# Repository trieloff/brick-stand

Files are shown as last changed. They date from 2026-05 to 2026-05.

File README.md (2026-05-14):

# brick-stand

Tenting stand for the [ZSA Voyager](https://www.zsa.io/voyager) split keyboard, designed parametrically with [ForgeCAD](https://github.com/KoStard/ForgeCAD).

## Reference geometry

`reference/` contains STL files used as design references — not part of the printable stand:

- `bottom_plate_left.STL` / `bottom_plate_right.STL` — official ZSA Voyager bottom shells (from <https://www.zsa.io/assets/voyager/voyager_stl.zip>)
- `ZSA Voyager Tripod Mount.stl` — [mark's tripod mount](https://www.printables.com/model/607727-zsa-voyager-tripod-mount), reference for the magnet + guide-pin mating pattern

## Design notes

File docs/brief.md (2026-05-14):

# Build Brief — The Brick

A monolithic tenting stand for the ZSA Voyager split keyboard, code-named **The Brick**. Prototyped in FDM print, intended for production as a single-piece stainless steel block (machined billet or investment cast + finish-machined).

## Operating story

Personal product-design project by the designer, Lars Trieloff. The Brick replaces the Voyager's stock magnetic legs with a substantial, monolithic base that holds the keyboard at the designer's measured-from-life typing posture. The prototype is FDM-printed in PLA/PETG for fit validation; the production target is a single-piece stainless-steel base per half — heavy, monolithic, finished. The name is literal: it should look and feel like a brick of metal, not a printed gadget.

**Anti-generic bar:** This is *not* a printable hobby wedge. The brick exists because the designer wants a piece of bench-grade desk hardware: it should feel inevitable, machine-honest, and look as good cast in steel as it does printed in plastic.

## Artifact classification

- **Family:** fixture / personal product, monolithic mating-and-supporting part. Not a mechanism — no moving parts, no assembly.
- **Manufacturing posture (prototype):** FDM print, PETG preferred (PLA acceptable), hollowed with infill.
- **Manufacturing posture (production):** single-piece stainless steel — 3-axis CNC from billet, or investment cast + finish-machined on critical mating surfaces. The geometry must be honestly producible in both processes.
- **Duty:** general-duty (desk use, occasional removal, must survive being dropped on tile from desk height when steel).
- **Scale:** compact (one per keyboard half, fits within keyboard footprint).
- **Cost posture (prototype):** balanced. **Cost posture (production):** performance-first (the brick *is* the cost statement).

## Posture (measured from the designer's current setup)

Left half, three corners measured against desktop:

| Corner | Z above desk |
|---|---|
| Front-left (outer / pinky) | **0 mm** (touching desk) |
| Rear-left (USB-port side) | **17 mm** |
| Front-right (inner / thumb) | **79 mm** |
| Rear-right (derived from plane) | **~96 mm** |

Right half is mirrored.

Derived plane:

- **Tent angle (rotation about front-rear axis):** atan(79 / 138) ≈ **29.8°**, outer-pinky-low, inner-thumb-high.
- **Tilt angle (rotation about left-right axis):** atan(17 / 137) ≈ **7.1°**, rear-raised (typewriter / positive tilt).
- Combined plane normal: `(10823, 2346, -18906)` (unnormalized) in keyboard-local frame.

These angles are **fixed** in the design — no adjustment mechanism. The brick *is* the angle.

## Attachment interface — official ZSA tripod-mount pattern

The brick replicates the interface of ZSA's own tripod-mount plate (which the designer owns and measured). Centered at **(63.10, 81.90)** in the left-half frame. See `docs/geometry-facts.md` for verified positions.

- **4 registration pegs**, Ø 2.15 mm × 1.5 mm tall, at the corners of a **33.26 × 33.26 mm square**. Slip-fit into the four small receptacles in the Voyager bottom plate (verified at z=0.11 in the reference STL).
  - Prototype: pegs printed integral to the brick body.
  - Production: pegs machined integral to the stainless body (or, alternatively, press-fit dowel pins into reamed holes if 3-axis CNC can't reach such fine integral features cleanly; pin choice deferred to manufacturing review).
- **4 magnets**, Ø 5 mm × 2 mm N42 neodymium, in a diamond pattern at **r = 9 mm from zone center**, at the four cardinal directions. Magnet midpoint-to-midpoint between opposing magnets = 18 mm. Pockets are Ø 5.1 mm × 2.1 mm deep, in the top mating face. Magnets pull against the corresponding magnets / steel pucks ZSA placed in the keyboard at matching positions.
- **No central feature engaged.** The keyboard has a ~Ø 3.8 mm tripod-screw recess at the zone center; the brick does not engage this.

The four corner pegs handle XY registration and anti-rotation. The four diamond magnets handle Z retention. No additional alignment features are needed.

## Geometry constraints

- **Footprint envelope:** matches the full Voyager half's vertical projection — 138 × 137 mm. The brick fills the entire shadow under the keyboard. This is intentional: the keyboard sits flush on the brick along its whole base, the brick reads as a chunky block of metal, and the "brick" identity is preserved.
- **Top face:** a single tilted plane at the measured posture, matching the keyboard's bottom plane exactly. Surface continuous edge-to-edge (no raised mating pad — the keyboard rests on the entire top face, with the attachment features sunk into a centered 38 × 38 mm zone).
- **Mating zone** (centered at (63.10, 81.90) in keyboard coords): 4 pegs at the 33.26 × 33.26 mm square corners stick up 1.5 mm from the top face; 4 magnet pockets (Ø 5.1 × 2.1) recessed into the top face in the diamond pattern.
- **Base face:** parallel to the desktop (Z = 0 plane), full flat contact across the whole footprint.
- **Body:** swept/filled volume between top plane and base, with the visual language of a solid milled block — chamfered top edges (2 mm × 45° for steel, 1.5 mm fillet for FDM), perimeter corner radii 6 mm, no visible draft, no decorative ribs. Corner heights: front-pinky 0 mm, rear-pinky 17 mm, front-thumb 79 mm, rear-thumb ~96 mm.
- **Prototype-only:** internal hollowing for FDM printability — target ~3 mm shell wall. External geometry must remain identical to production.
- **Production:** solid stainless steel. Optional machined recess on the bottom (5 mm deep, 5 mm perimeter wall) for mass and 4-point desk contact.

## Feet / desk interface

- Four counter-bored pockets (Ø 10 mm × 2 mm deep) on the bottom face at the four base corners, sized for **3M Bumpon SJ5012** or similar urethane bumper feet. Same pattern for both prototype and production.

## Variant policy

- Single ForgeCAD project produces both halves via a `Side` parameter (`"left"` / `"right"`). Right is a mirror of left about the X axis.
- A `Process` parameter selects `"FDM-prototype"` (hollowed) vs `"steel-production"` (solid with optional bottom recess). Both share the same external geometry.
- Default render: one selected variant at a time. A `Show pair` debug mode renders both halves side-by-side for posture inspection, but collision/manufacturing inspection always runs on one selected variant.

## File organization

Multi-file ForgeCAD project:

- `main.forge.js` — entry point. Top-level `assembly()` selects variant via params, places either one or both halves, renders.
- `brick.forge.js` — the brick geometry itself, parameterized by `Side` and `Process`.
- `voyager_mockup.forge.js` — a low-detail proxy of the Voyager bottom plate (extracted bounding box + corner pin/magnet pattern) used only for collision and posture inspection. Not part of the final BOM.
- `geometry.js` — pure helpers and constants (measured corner heights, magnet pattern, derived plane normal). Plain `.js`, no rendered geometry.

## BOM (production part — one half)

| Item | Spec | Qty | Notes |
|---|---|---|---|
| Brick body | 316 or 304 stainless steel, single piece | 1 | CNC from billet OR investment cast + finish-machined on top mating face, peg posts, magnet pockets, bottom |
| Neodymium magnet | Ø 5 mm × 2 mm, N42, axially magnetized | 4 | Press-fit or epoxy into pockets; polarity to match the keyboard's internal magnets at the same positions |
| Urethane bumper foot | 3M Bumpon SJ5012 (black, Ø 10 × 2 mm) | 4 | Self-adhesive into bottom pockets |

(Prototype BOM: printed body with integral pegs, same magnets, same feet. The 4 corner pegs are integral to the body in both processes — no separate dowel pins.)

## Validation criteria

- Top face places the four Voyager corners at 0/17/79/~96 mm ± 0.5 mm against a flat desk.
- 4 corner pegs fall on the 33.26 × 33.26 mm square at (63.10, 81.90) ± 0.1 mm, slip-fit into the keyboard's peg receptacles.
- 4 magnet pockets at the cardinal r=9 mm positions ± 0.1 mm.
- No collision between brick top face and Voyager underside other than the intended flush contact.
- Center of mass over the base footprint with at least 10 mm safety margin in all directions when keyboard is mounted (tip-over check at 29.8° tent).
- Wall thickness ≥ 3 mm everywhere in the FDM prototype shell. Minimum cross-section ≥ 5 mm everywhere in the production solid.
- Magnet pockets: Ø 5.1 mm × 2.1 mm depth (press-fit). Peg shafts: Ø 2.15 mm × 1.5 mm tall.
- Bottom face flat to ± 0.2 mm prototype / ± 0.05 mm production.

## Final state target

**`BUILD-READY` for the prototype**, **`BEST-EFFORT BUILD CANDIDATE` for production** — the steel manufacturing review (CNC vs cast + finish, integral pegs vs press-fit dowels) needs a real shop quote before final lock.

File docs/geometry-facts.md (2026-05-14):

# Geometry facts (extracted from reference STLs)

All in millimeters, in the **Voyager-left-half local frame** of `reference/bottom_plate_left.STL`:

- **Footprint:** X 0 .. 137.85 (pinky → thumb), Y 0 .. 136.87 (front → rear), plate thickness 2.3 mm.
- **Pinky edge:** X = 0. **Thumb edge:** X = 137.85.
- **Front edge:** Y = 0. **Rear edge:** Y = 136.87.
- The Voyager-right half is the mirror of the left about the X axis.

## ZSA tripod-mount interface (the brick's attachment target)

ZSA ships an official tripod-mount plate (~38 × 38 mm, owned by the designer). It mates centrally to the keyboard via four corner pegs and four diamond-pattern magnets. The brick replicates this same interface on its top face.

**Zone center:** (63.10, 81.90) in left-half frame.

### Peg receptacles (verified in STL)

Four small circular features at z ≈ 0.11 mm, Ø ~2.2 mm, on the corners of a **33.26 × 33.26 mm square** around the zone center:

| Position | (X, Y) |
|---|---|
| Front-pinky corner | (46.50, 65.30) |
| Front-thumb corner | (79.70, 65.30) |
| Rear-thumb corner | (79.70, 98.50) |
| Rear-pinky corner | (46.50, 98.50) |

The brick's matching pegs are ~Ø 2.15 mm × 1.5 mm tall (slip-fit into the keyboard receptacles).

### Magnets (per the designer's measurements of the ZSA mount plate)

Four magnets, **Ø 5 mm**, in a diamond rotated 45° from the corner-peg square. **Midpoint-to-midpoint distance between opposing magnets ≈ 18 mm**, so each magnet sits at **r = 9 mm** from the zone center, at the four cardinal directions:

| Direction | (X, Y) |
|---|---|
| Rear (Y+) | (63.10, 90.90) |
| Thumb (X+) | (72.10, 81.90) |
| Front (Y−) | (63.10, 72.90) |
| Pinky (X−) | (54.10, 81.90) |

These positions are not visible in the bottom-plate STL (magnets are embedded internally, flush with the inner face). Verified geometrically against the designer's measurements of the ZSA tripod-mount plate; depends on the assumption that ZSA placed corresponding magnets in matching positions.

### Central feature

A small (~Ø 3.8 mm) feature at the zone center, likely a tripod-screw recess. The brick top face does not need to engage this — it is irrelevant for the brick's attachment.

### Legacy: magnetic leg sockets (NOT used by the brick)

Two Ø 16.5 mm sockets at (119.24, 13.66) and (105.40, 114.36) accept the stock folding magnetic legs. The brick **replaces** the legs, so these sockets are not engaged.

## Measured posture (user-reported corner heights above the desk)

Mapped from user phrasing to the STL frame:

| Corner | (X, Y) | Z above desk |
|---|---|---|
| Front-pinky ("front-left") | (0, 0) | 0 mm (touching desk) |
| Rear-pinky ("rear-left, USB-port") | (0, 136.87) | 17 mm |
| Front-thumb ("front-right") | (137.85, 0) | 79 mm |
| Rear-thumb (derived) | (137.85, 136.87) | ~96 mm |

## Derived mating plane (in desk frame)

The keyboard's bottom face lies on the plane through those four corners. Closed form:

```
z(x, y) = a*x + b*y
a = 79 / 137.85   ≈ 0.57309
b = 17 / 136.87   ≈ 0.12421
```

- **Tent angle (rotation about Y, front-rear axis):** atan(a) ≈ **29.81°**, thumb-up.
- **Tilt angle (rotation about X, pinky-thumb axis):** atan(b) ≈ **7.08°**, rear-up.
- **Plane normal (toward desk):** proportional to (a, b, −1) = (0.57309, 0.12421, −1).

## Mating-pad heights in posture

The brick's top mating pad sits on the keyboard's bottom plane at the tripod-mount zone center and corners. Z above desk at each:

- **Zone center** (63.10, 81.90): z = 0.57309 · 63.10 + 0.12421 · 81.90 ≈ **46.2 mm**
- Front-pinky corner (46.50, 65.30): z ≈ **34.8 mm**
- Front-thumb corner (79.70, 65.30): z ≈ **53.8 mm**
- Rear-thumb corner (79.70, 98.50): z ≈ **57.9 mm**
- Rear-pinky corner (46.50, 98.50) z ≈ **38.9 mm**

The mating pad (~38 × 38 mm) sits on a tilted plane at these heights and tapers down on a tapered pedestal to the wider desk-contact base.

## Bumper feet pattern (Brick's bottom face)

Four feet, 5 mm inset from each Brick corner, suitable for 3M Bumpon SJ5012 (Ø 10 mm).

## Right-half mirror

To produce the right Brick, mirror everything about X (in the **Voyager-pair** frame where the two halves meet at the user's centerline). The footprint, sockets, and corner-height pattern flip; sign of `a` flips, `b` stays.

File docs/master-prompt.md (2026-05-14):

# Master Prompt — Modeling Pass

```text
You are producing a ForgeCAD build-ready physical artifact package, not a concept sketch.

Treat this as a serious product-team prototype assignment.
The goal is to produce a credible internal engineering package for a real build candidate, not a generic maker example.

Target artifact:
- artifact: monolithic tenting base ("The Brick") for the ZSA Voyager split keyboard, one part per half (mirrored).
- request summary: design a fixed-angle tenting stand that holds the user's measured posture and is honestly producible both as a hollowed FDM print and as a single-piece stainless steel block.
- normalized interpretation: a rigid wedge with a planar upper mating face (Voyager interface) and a planar lower base face (desk interface). No moving parts. Magnet + guide-pin attachment replaces the stock Voyager legs.

Specific operating story:
- organization / team: personal product-design project by the designer (no invented employer).
- project / prototype revision: "Brick v0.1" — first geometry pass for fit validation.
- milestone / review moment: working FDM print at the designer's desk, validated against the in-use Voyager; then sourcing quote for single-piece stainless production.
- domain context: ergonomic keyboard accessories / custom desk hardware.
- production reason: replace stock Voyager magnetic legs with a substantial, monolithic base at a specific measured posture.
- test setting: designer's desk, real Voyager keyboard, real typing session.
- generic-output failure mode to avoid: a printable hobby wedge with hollow ribs that visibly screams "FDM" — must look credible cast or machined in steel.
- benchmark class / public comparison anchor: ZSA's official Voyager printables for the interface pattern; "Brick"-class desk hardware aesthetic (single milled block, chamfered edges, generous radii).

Chosen intake classification:
- artifact family: fixture / personal product, monolithic mating-and-supporting part (no mechanism).
- duty level: general-duty.
- scale level: compact (≤ 138 × 137 mm per half).
- cost posture: balanced for prototype, performance-first for production.
- job style: single-piece replacement for the stock Voyager legs.
- manufacturing / process stack: prototype = FDM (PETG preferred, 3–4 mm shell, 15–25 % infill); production = single-piece 304/316 stainless steel via 3-axis CNC from billet, or investment cast + finish-machined on the mating face, magnet pockets, pin holes, and bottom.
- budget posture: prototype cheap, production "as-good-as-it-deserves".

Working assumptions chosen to close missing inputs:
- these assumptions are provisional and family-scoped; they apply to monolithic fixtures / personal product, not as universal defaults.
- Posture is fixed at the designer's measured corner heights: (front-outer, rear-outer, front-inner, rear-inner) = (0, 17, 79, 96) mm on a 138 × 137 mm footprint. Tent ≈ 29.8°, tilt ≈ 7.1° rear-raised.
- Attachment: 5 × Ø10×3 mm N42 magnets press-fit into pockets on the mating face, 4 × Ø3×6 mm hardened dowel pins press-fit (production) or printed integral (prototype). Pattern positions extracted from `reference/bottom_plate_left.STL` — to be verified during implementation.
- Feet: four Ø10×2 mm bottom pockets for 3M Bumpon SJ5012 urethane bumpers.
- External geometry is identical between prototype and production; only the *internal* hollowing differs (prototype = offset shell, production = solid or with optional bottom recess).

Hard constraints:
- use ForgeCAD.
- no `assembly()` for a moving mechanism is required — there is no mechanism. Use `assembly()` only to compose the brick + Voyager mockup for inspection.
- the brick is one solid body; do not split it into multiple parts that would have to be joined.
- choose manufacturing/processes that fit a single-piece stainless production part: no undercuts unreachable by a 3-axis mill from top + bottom, no internal voids that an investment-cast pattern could not realize, no thin protrusions < 3 mm wall.
- include realistic process-appropriate clearances on the magnet pockets and pin holes for both prototype (looser, accommodate FDM expansion) and production (H7 press-fit).
- include manufactured, printed, and purchased parts only where each is an honest choice.
- include a BOM that is concrete enough to buy and assemble from.
- do not hide uncertainty; choose defaults and continue.
- do not claim the designer works for a named company.
- do not clone proprietary named products; mark's tripod mount is a *pattern reference* for the magnet/pin interface, not a design to copy.

Acceptable final states:
1. `BUILD-READY` once the magnet/pin pattern is extracted and verified against the Voyager bottom-plate STL.
2. `BEST-EFFORT BUILD CANDIDATE` if the pattern extraction is approximate.

Required outputs:

0. Operating story and anti-generic bar — already stated above.
1. Problem normalization — already stated above.
2. Assumption bundle — already stated above.
3. Architecture choice
   - One monolithic wedge per half. Upper face = measured-posture plane. Lower face = desk plane (Z=0). Body = swept solid between them, clipped to a chamfered-and-radiused prismatic outline.
   - Rejected: adjustable hinge mechanism (no need, posture is fixed); two-part stacked wedges (defeats the "brick" identity and adds an interface that wants to wobble); minimal three-point post stand (no mass, fails the "feels like a brick" criterion).
4. Detailed mechanical design
   - Footprint outline: chamfered rectangle inscribed in the Voyager projection. Corner radii 6 mm. External top edges chamfered 2 mm × 45° on production, fillet 1.5 mm on prototype (FDM aesthetic).
   - Mating face: defined by the four measured corner heights. Pattern of 5 magnet pockets and 4 pin features mirrors the Voyager bottom-plate sockets.
   - Base face: flat, parallel to desk, with four feet pockets at the corners and (production only) an optional bottom recess.
   - No motion ranges, no joints, no stops.
5. Actuation and transmission — not applicable. The brick is static.
6. Manufacturing package
   - Prototype: FDM, brick lying mating-face-up so the magnet pockets print with clean ceilings via bridging, the base face prints flat against the bed for dimensional accuracy. Single-shell vase-mode-style 3 mm wall thickness, 15 % gyroid infill in a top zone for stiffness. Pin features printed integral, no support required if oriented correctly. Print sensitivities: bottom flatness (first-layer squish), magnet pocket diameter (FDM tends to over-shrink small features — add 0.2 mm radial allowance).
   - Production: 3-axis CNC from a 304 or 316 stainless billet. Two setups: top-down for the angled mating face, magnet pockets, pin reaming, and side chamfers; bottom-up for the base recess and feet pockets. Investment casting alternative: cast near-net, finish-machine the mating face flat-and-true, ream pin holes, drill/bore magnet pockets, surface-grind base flat.
7. Bill of materials — see `docs/brief.md` BOM table. Reproduce inline in the implementation output.
8. Assembly package
   - Production: press magnets into pockets (light tap with arbor press, witness mark on polarity); press dowel pins; peel-and-stick urethane feet onto bottom pockets.
   - Prototype: same, except pins are printed integral so only magnets and feet are pressed/stuck.
9. Validation package
   - Verify mating face places the four Voyager corners at 0/17/79/96 mm ± 0.5 mm.
   - Render-inspect with the Voyager mockup mounted: no collision with USB-C cable strain relief, no collision with the per-half cable boss.
   - Tip-over check: center of mass projected onto base must lie ≥ 5 mm inside the base outline in all directions.
   - Wall thickness: ≥ 3 mm prototype shell, ≥ 5 mm production minimum cross-section.
   - Compare both rendered halves to ensure mirror correctness.
10. ForgeCAD implementation package
    File structure:
    - `main.forge.js` — runnable entry point. Params: `Side` (left/right), `Process` (FDM-prototype / steel-production), `ShowVoyagerMockup` (boolean), `ShowPair` (boolean, debug). Returns either one brick, one brick + mockup, or both bricks side-by-side.
    - `brick.forge.js` — `function brick({ side, process })` returning the solid.
    - `voyager_mockup.forge.js` — `function voyagerMockup({ side })` returning a thin proxy plate at the measured posture.
    - `geometry.js` — pure constants: `CORNER_HEIGHTS_MM`, `FOOTPRINT_MM`, `MAGNET_PATTERN`, `PIN_PATTERN`, `MATING_PLANE_NORMAL`, mirror helper.
    Use `bom()` to declare magnets, pins, feet, and the body. Export STL for prototype, STEP for production.
11. Final verdict
    - `BEST-EFFORT BUILD CANDIDATE` until the magnet/pin pattern is extracted from the Voyager STL with verified positions.

ForgeCAD-specific quality bar:
- The brick is static; no joints required.
- Use `assembly()` only to compose brick + Voyager mockup for inspection — clearance logic must be physically honest there.
- A pretty rendered wedge is not success. Success = collision-clean inspection bundle against the Voyager mockup, all four corner heights verified, and a BOM that someone could quote against today.
```

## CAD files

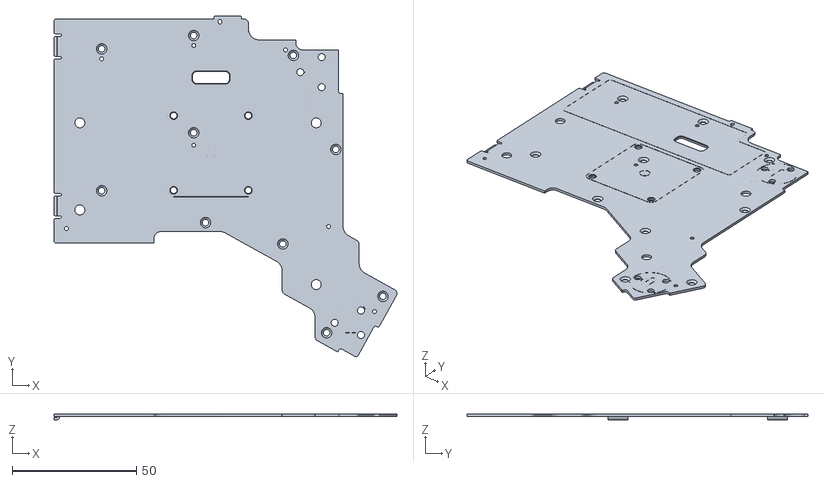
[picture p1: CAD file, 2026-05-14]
reference/bottom_plate_right.STL
137.8 x 136.9 x 2.32

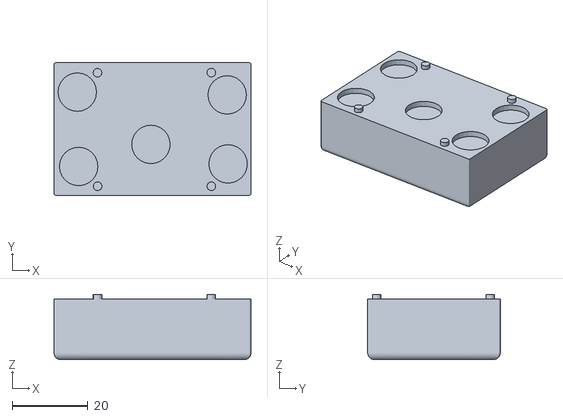
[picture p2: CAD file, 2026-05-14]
reference/ZSA Voyager Tripod Mount.stl
52.0 x 35.0 x 17.2

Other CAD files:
reference/bottom_plate_left.STL

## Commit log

2026-05-14 Initial commit: Voyager tenting stand project scaffold
    Reference STLs from ZSA (shell) and Printables (tripod mount).
    ForgeCAD skills installed via upskill from KoStard/ForgeCAD.
    [ZSA Voyager Tripod Mount.stl, bottom_plate_left.STL, bottom_plate_right.STL]
2026-05-14 Add build brief and master prompt for The Brick
    Captures measured posture (29.8° tent, 7.1° rear-raised tilt from corners
    0/17/79/96 mm), monolithic single-piece brief, FDM-prototype and
    stainless-steel-production paths, 5-magnet + 4-pin attachment, BOM, and
    validation criteria.
2026-05-14 Add extracted geometry facts
    Two Ø16.50 mm magnetic leg sockets (not the 5-magnet/4-pin pattern of
    mark's tripod mount). Front socket (119.24, 13.66) terminates at 70.0 mm
    above desk; rear socket (105.40, 114.36) at 74.6 mm. Mating plane
    parameters and bumper-feet locations included.
2026-05-14 Switch attachment to ZSA tripod-mount interface
    The 2 large sockets at (105, 114) and (119, 14) are for the foldable
    magnetic legs, not the tripod mount. The actual tripod-mount interface
    is centered at (63.10, 81.90): 4 peg receptacles at the corners of a
    33.26 mm square, plus 4 internal magnets in a diamond at r=9 mm.
    Brick design updated: 4 integral pegs + 4 Ø5 mm magnets in the central
    mating zone, full-footprint solid wedge, keyboard rests flush on the
    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
2026-05-14 First brick model — tripod-mount interface, full-footprint wedge
    main.forge.js: entry point, params for Side and viewing modes, BOM.
    brick.forge.js: full-footprint wedge body, 4 integral pegs and 4
    magnet pockets on the tilted top face, oriented along the keyboard
    plane normal.
    voyager_mockup.forge.js: thin mockup plate for posture inspection.
    geometry.js: all constants and helpers, posture plane,
    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
2026-05-14 Add Detail param: preview/features/finished
    The Manifold/Truck WASM kernel that runs in the studio collapses on the
    trimByPlane + boolean cascade — even the bare wedge with mount features
    takes 2+ minutes there, well past the 30s studio timeout. OCCT (CLI)
    handles it in ~1s but isn't available in-browser.
    Detail=preview (default) renders only the trimmed wedge (~70ms in
    WASM); studio-friendly. Detail=features adds pegs/pockets/feet.
    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
2026-05-14 Preview pegs as separate cylinders via group()
    Returning pegs as group() children (not unioned into the body) keeps
    the WASM kernel happy, and using a single cylinder per peg in preview
    (no sphere cap) drops the build from 31s to 134ms.
    Sphere-capped pegs (the production look) still kick in for
    Detail=features and Detail=finished.
2026-05-14 Preview magnets as brass-colored discs
    Skip the pocket subtracts (the kernel-killer in WASM) and instead
    render the magnets themselves flush with the tilted top face. Visually
    equivalent to seeing the pocket positions, ~180ms total.
    Real subtractive pockets still kick in for Detail=features/finished.
2026-05-14 Add Hollow param: 3mm shell inset wedge
    In preview the cavity ships as a separate dark child shape inside the
    group — visible as a dark inner solid, no boolean cost. In features/
    finished modes the cavity is actually subtracted (CLI+OCCT), giving a
    real hollow shell. Wall thickness 3 mm on every face.
    The 3 mm ceiling under the tilted top face leaves 0.9 mm of material
    above the magnet pockets (depth 2.1 mm), and the 3 mm base leaves
    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
2026-05-14 Translucent body in hollow preview
    So the cavity child shows through. Uses .material({opacity: 0.35}).
    Wireframe sees both surfaces; solid view sees the cavity ghosting
    inside the brick.
2026-05-14 Add per-side export wrappers (Detail=finished, Hollow=1)
    forgecad export stl doesn't accept -p param overrides, so wrappers
    pin the params via require()'s overrides argument. Run:
    forgecad export stl _export_left.forge.js --output output/brick-left-hollow.stl --backend occt --quality high
    forgecad export stl _export_right.forge.js --output output/brick-right-hollow.stl --backend occt --quality high
2026-05-17 Import real ZSA bottom plate as Voyager mockup
    importMesh() of reference/bottom_plate_left.STL gives the actual
    outline, true peg receptacle positions, and the trackball-mount step,
    all at once. Mirror for right side as before.
    Enables visual alignment: toggle ShowVoyagerMockup=true in the studio
    to see the keyboard sitting on the brick.
2026-05-17 Match real Voyager outline; add PegSpacing slider
    Three iteration tools for visual alignment against the imported
    keyboard mockup:
    - Brick footprint now traces the real Voyager outline (63-vertex
    polygon extracted from the bottom-plate STL) — preserves the
    stepped silhouette so the brick hides under the keyboard.
    - PegSpacing is now a slider, default 35 mm (user-measured against
    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
2026-05-17 Project the keyboard outline onto the desk for the brick footprint
    The brick was extruded from the keyboard's untilted outline straight
    up, then trimmed by the slanted plane. Top XY footprint stayed full
    size, but the keyboard at posture projects shorter in X (by cos tent)
    and shifts in Y (by an X-cross term). Brick overhung the keyboard.
    Fix: project every outline vertex (and peg/magnet center) through the
    same tent+tilt rotation that voyager_mockup applies, taking just XY.
    The brick's shadow now equals the keyboard's shadow at posture.
    Cavity sizing tracks the projected bbox so it stays inside the
    shorter footprint.
    Si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
2026-05-17 Reserve a 20×80×3 mm Navigator bar zone
    Bar sits flush under the keyboard along the thumb/index edge of each
    half. Built in keyboard-local frame, rotated into posture, then either
    rendered as an orange visualization (preview) or subtracted from the
    body (features/finished).
    Params: ReserveNavigator (bool, default on) and NavigatorY (slider,
    0..137, default 68.5 mm = middle of the keyboard length).
2026-05-17 Tune peg spacing to 29.5 mm, diameter to 1.65 mm
    Both based on visual inspection against the imported Voyager STL.
    35 mm was the user's initial measurement against the physical ZSA
    mount plate; on screen the receptacles sit at 29.5 mm. Peg diameter
    shrinks by 0.5 mm so the pegs slip into the receptacles.
2026-05-17 PegSpacing default 30.0 mm (measured from STL holes)
    Exact receptacle centers extracted from bottom_plate_left.STL bottom
    face: (48.099, 66.911), (78.099, 66.911), (48.099, 96.911), (78.099,
    96.911) — perfect 30 × 30 mm square on the existing mount-zone center
    (63.099, 81.911).
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2026-05-17 Subtract Navigator pocket in preview; hide the bar
    Navigator clearance (21 × 81 × 4 mm, the 20 × 80 × 3 actual bar plus
    0.5 mm margin on every face) is now subtracted from the body in ALL
    modes — the preview shows the final pocket directly without rendering
    the bar separately. Single box.subtract on the trimmed body is fast
    (~750 ms total in WASM).
    Defaults: NavigatorX 105, NavigatorY 66 (user-tuned positions).
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2026-05-17 Fix Navigator cut: extend only outward, not inward
    box() is centered on XY, so OUTWARD_EXTEND grew the cut equally in +X
    and -X, eating into the body's inner side. Shift the box center by
    OUTWARD_EXTEND/2 in +X so the inner face stays put and only the outer
    face extends past the wall.
2026-05-17 Foot pockets: pin to keyboard-local interior points
    Projected-bbox corners fell outside the non-rectangular silhouette
    (only one or two pockets landed on the body). Replaced with four
    hand-picked keyboard-local points known to be inside the outline,
    then projected to desk XY.
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2026-05-17 Split FDM/CNC exports; chamfer every convex outer edge
    Four export wrappers replace the previous two:
    _export_{left,right}_fdm.forge.js PegDiameter 2.3, Hollow on
    _export_{left,right}_cnc.forge.js PegDiameter 2.5, Hollow off
    PegDiameter is now a Param overridable from require() so the same
    brick.forge.js produces both variants. FDM uses 2.3 mm to compensate
    for typical FDM over-extrusion; CNC uses 2.5 mm for a ~50 µm slip-fit
    into the keyboard's Ø2.6 mm receptacles.
    Chamfered every convex outer-body edge (length ≥ 4 mm) at 0.6 mm.
    Whole-set chamfer crashed OCCT on shared corner vertices; per-edge
    chamfer in a try/catch loop applied 99 of 108 edges and skipped the
    degenerate cor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
